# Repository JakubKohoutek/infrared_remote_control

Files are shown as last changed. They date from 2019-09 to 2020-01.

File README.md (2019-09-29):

# Infrared Remote Control

This repository contains circuit diagram and code for low power infrared remote control using Arduino.

## Circuit Diagram

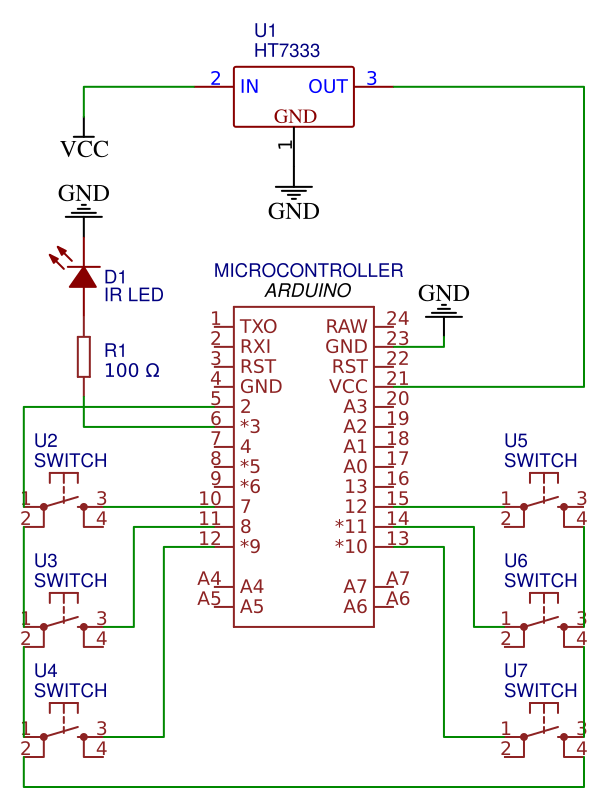
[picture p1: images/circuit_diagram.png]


## Adjustments To Minimize Power Consumption

I was able to lower the power consumtion of Arduino Pro Mini to 20µA (0.02mA) by:

* Desoldering the always-on power LED
* Desoldering on board voltage regulator and using the HT7333-A voltage regulator instead (with quiescent current around 8µA)
* Utilizing the deep sleep mode using the [LowPower library by rocketscream](https://github.com/rocketscream/Low-Power)

Useful articles on minimizing power consumption of arduino I used as inspiration for my code:

* [How to modify an Arduino Pro Mini (clone) for low power consumption](https://andreasrohner.at/posts/Electronics/How-to-modify-an-Arduino-Pro-Mini-clone-for-low-power-consumption/)
* [Arduino low power - How to run ATMEGA328P for a year on coin cell battery](http://home-automation-community.com/arduino-low-power-how-to-run-atmega328p-for-a-year-on-coin-cell-battery/)

## Overcoming Limited Number Of External Interrupts

During the development, I encountered an issue when lowering the power consumption. I utilized the deep sleep mode that awakes Arduino using external interrupt pins, but there are only two such pins on Arduino Pro Mini. I wanted to have at least 6 buttons, so I had to solve this obstacle somehow.

In most projects, they solve it by having a dedicated "wake up" button. This button is connected to the interrupt pin and awakes arduino from sleep mode. Arduino stays awake for some time to perform required operations and then it is sent to sleep mode again after certain time of inactivity. I decided not to go this way as it would usually mean to press two buttons to send one command.

Instead, I got inspired by [this article](https://create.arduino.cc/projecthub/Svizel_pritula/10-buttons-using-1-interrupt-2bd1f8) that utilizes the fact that Arduino can reconfigure its pins at any time.

It uses two modes

* **Interrupt mode** - in this mode, all buttons are connected to an interrupt pin (set as `INPUT_PULLUP`) on one side and to their own individual pins on other side (set all as `OUTPUT` to `LOW`). After this configuration is set, Arduino enters the sleep mode and waits for a button press. Once any button is pressed, interrupt pin is set to `LOW`, sleep mode is terminated and Arduino rewires internally to distinct mode.
* **Distinct mode** - in this mode, interrupt is detached from an interrupt pin and the pin is reconfigured to `OUTPUT` and set to `LOW`, while all button pins are changed to `INPUT_PULLUP`. In this configuration we can easily find out what button has been pressed and send the corresponding code.

## The Finished Product

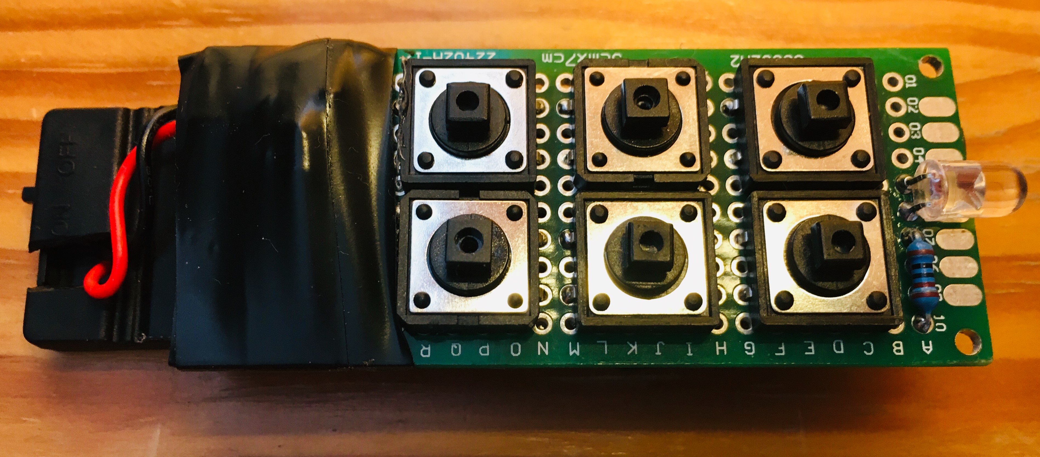
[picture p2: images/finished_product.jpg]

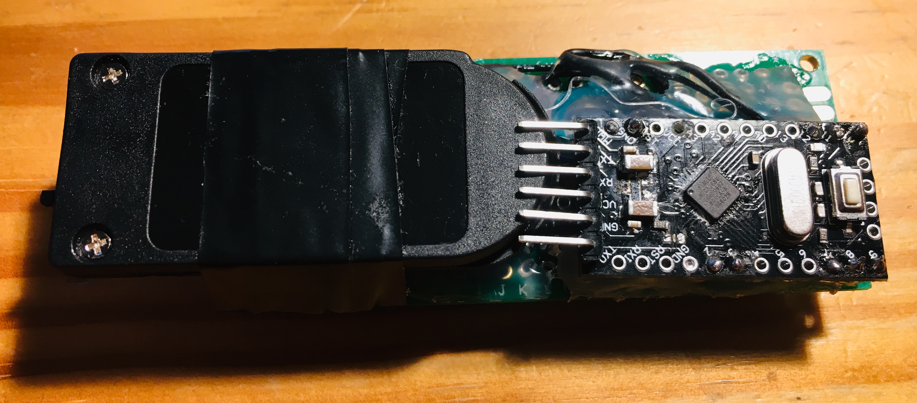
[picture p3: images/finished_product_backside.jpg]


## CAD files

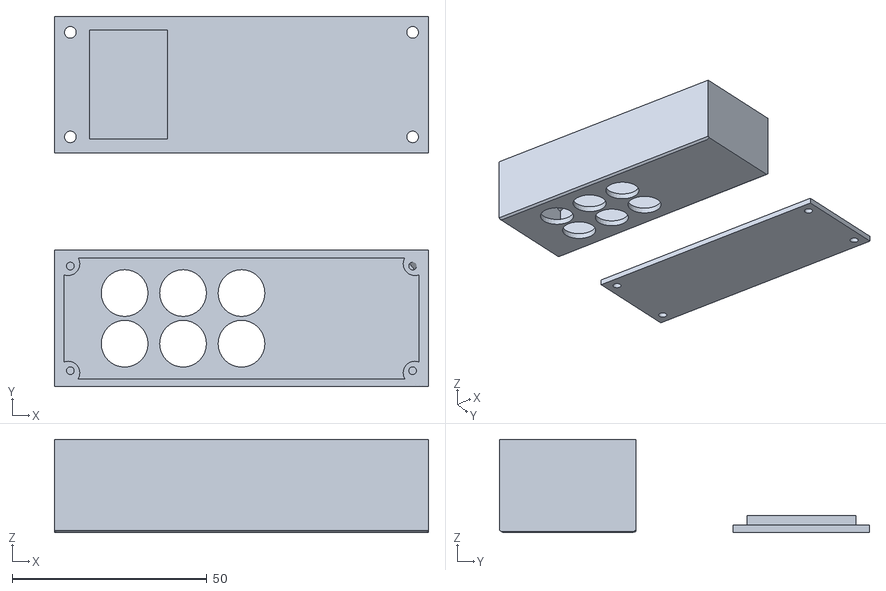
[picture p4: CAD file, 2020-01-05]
case_3d_model/remote_control_final.stl
96.0 x 95.0 x 24.0

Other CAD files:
case_3d_model/remote_control.blend

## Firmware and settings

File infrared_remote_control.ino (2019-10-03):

#include "SendMitsubishiCode.h" // custom extension of https://github.com/z3t0/Arduino-IRremote => uses pin D3
#include "LowPower.h"           // library by rocketscream, https://github.com/rocketscream/Low-Power

// Codes for IR remote control
#define CODE_WIN          0x2F9C
#define CODE_HDMI         0x2F42
#define CODE_OFF          0x2F72
#define CODE_ON           0x2F4A
#define CODE_DPORT        0x2FAA
#define CODE_DVI          0x2F8C

const auto WAKEUP_FUNCTION = [](void){/* Do nothing, just wake up */};
const int  BUTTON_CODES[]  = {CODE_WIN, CODE_HDMI, CODE_OFF, CODE_ON, CODE_DPORT, CODE_DVI};
const int  BUTTON_PINS[]   = {7,        8,         9,        10,      11,         12      };
const int  INTERRUPT_PIN   = 2;

void setup() {
  Serial.begin(9600);

  // In default configuration all buttons are outputs set to low and we are checking
  // on interrupt pin (pulled up by internal resistor) if it set to ground
  configureInterruptMode();
}

void loop() {
  sleepUntilExternalInterrupt();

  // Change configuration to distinguish what button is actually pressed
  configureDistinctMode();

  // Find out what button has been pressed, send corresponding IR code and
  // wait until the button is released again
  for (int i = 0; i < sizeof(BUTTON_PINS) / sizeof(int); i++) { 
    if (digitalRead(BUTTON_PINS[i]) == LOW) {
      Serial.println(BUTTON_CODES[i], HEX);
      sendMitsubishiCode(BUTTON_CODES[i]);

      while(digitalRead(BUTTON_PINS[i]) == LOW) {
        delay(100);
      }
    }
  }

  // Return configuration to interrupt mode
  configureInterruptMode();
}

void sleepUntilExternalInterrupt(void) {
  Serial.println("Going to sleep");
  delay(100); // must delay, otherwise arduino can't send the message before it falls to sleep

  // Execute the deep sleep mode
  LowPower.powerDown(SLEEP_FOREVER, ADC_OFF, BOD_OFF);

  // Once interrupt is triggered, arduino wakes up and continues from here
  Serial.println("Waking up");
}

void configureInterruptMode(void) {
  pinMode(INTERRUPT_PIN, INPUT_PULLUP);
  attachInterrupt(digitalPinToInterrupt(INTERRUPT_PIN), WAKEUP_FUNCTION, LOW);
 
  for (int i = 0; i < sizeof(BUTTON_PINS) / sizeof(int); i++) {
    pinMode(BUTTON_PINS[i], OUTPUT);
    digitalWrite(BUTTON_PINS[i], LOW);
  }

  Serial.println("Configured interrupt mode");
}

void configureDistinctMode(void) {
  detachInterrupt(digitalPinToInterrupt(INTERRUPT_PIN));

  for (int i = 0; i < sizeof(BUTTON_PINS) / sizeof(int); i++) {
    pinMode(BUTTON_PINS[i], INPUT_PULLUP);
  }

  pinMode(INTERRUPT_PIN, OUTPUT);
  digitalWrite(INTERRUPT_PIN, LOW);
 
  Serial.println("Configured district mode");
}

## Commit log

2019-09-28 Create sketch for low power infrared remote control
2019-09-29 Add circuit diagram and include it in README
2020-01-05 Add 3d model for the remote control case
    [remote_control.blend, remote_control_final.stl]
2020-01-05 Improve 3d model
    [remote_control.blend, remote_control_final.stl]
